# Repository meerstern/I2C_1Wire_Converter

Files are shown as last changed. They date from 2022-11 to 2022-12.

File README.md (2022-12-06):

# I2C-1Wireマスタ変換基板
I2C_1Wire_Converter with DS2485

## 概要
  * [DS2485][1]とレベル変換回路を搭載したI2C-1Wireマスタ変換基板です  
  * I2Cスレーブを1Wireマスタに変換します  
  * タイミングがシビアな1WireデバイスをI2Cコマンドで容易に操作することが可能です  
  * DS2485のレジスタを変更することで1Wire通信のタイミングを細かく調整することが可能です  
  * DS2485は126バイトのバッファを備えており、効率良く1Wire通信をすることが可能です  
  * 本変換基板にはレベル変換回路を搭載しているため、5VレベルのI2C及び1Wireに対応しています  
  * DS2485のGPIOは電源入力のPchMOSFETに接続されています  
  * 電源入力のPchMOSFETを介して1Wireバスの強力プルアップを利用することが可能です  
  * I2Cの接続はGrove互換コネクタを使用しています  
  * 1Wireの接続はVCC、1Wire、GNDの2.54mmピッチターミナルコネクタを使用しています  
  * 1Wireの電源及び信号電圧レベルはGroveコネクタから供給する電源電圧に一致します  
  * 電源電圧：3.3V~5V
  * 基板サイズ25mm x30mm、固定穴M3x2 幅19mm
  
 ## 販売サイト
  * [スイッチサイエンス][2]
  
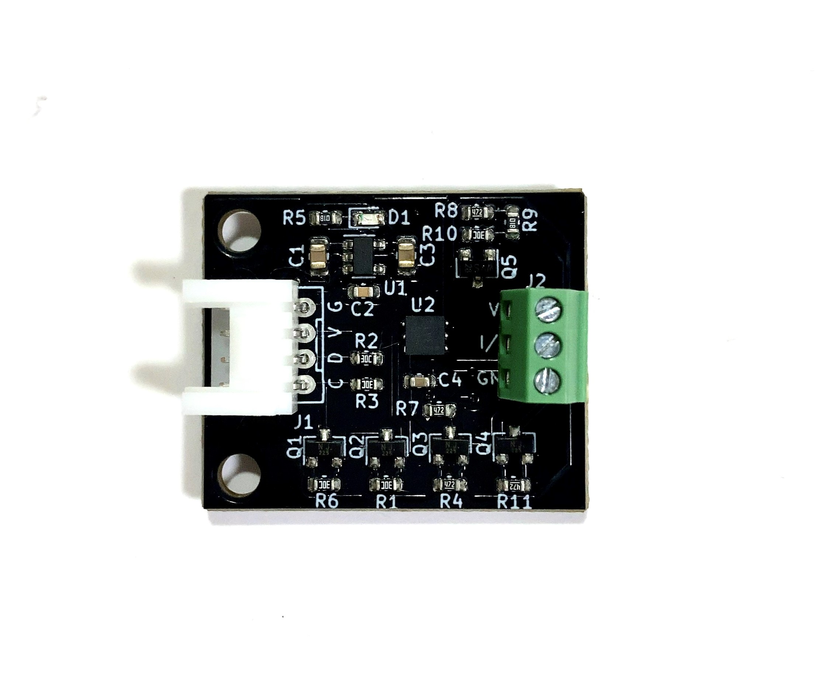
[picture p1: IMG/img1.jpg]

   
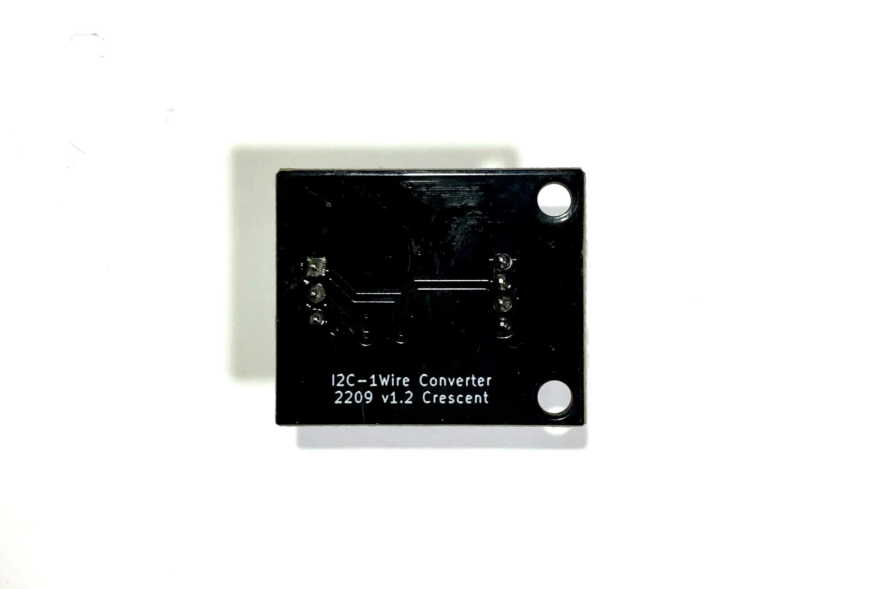
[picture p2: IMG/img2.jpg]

  
[1]: https://www.maximintegrated.com/jp/products/ibutton-one-wire/memory-products/DS2485.html
[2]: https://www.switch-science.com/products/8650

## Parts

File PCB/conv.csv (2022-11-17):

ID | 参照記号 | パッケージ | 数 | 名称 | Supplier and ref
1 | R11,R8,R7,R4 | R_0603_1608Metric | 4 | 4.7k
2 | R10,R6,R1,R3,R2 | R_0603_1608Metric | 5 | 10k
3 | R9,R5 | R_0603_1608Metric | 2 | 1k
4 | Q5 | SOT-23 | 1 | Q_PMOS_GSD
5 | Q4,Q3,Q2,Q1 | SOT-23 | 4 | Q_NMOS_GSD
6 | REF2,REF1 | MountingHole_3.2mm_M3 | 2 | MountingHole_3.2mm_M3
7 | U2 | TDFN6-EP | 1 | ds2485
8 | U1 | SOT-23-5 | 1 | LD3985M33R_SOT23
9 | J2 | PinHeader_1x03_P2.54mm_Vertical | 1 | Conn_01x03
10 | J1 | GROVE | 1 | Conn_01x04
11 | D1 | LED_0603_1608Metric | 1 | LED
12 | C4 | C_0603_1608Metric | 1 | 0.1u
13 | C3,C1 | C_0805_2012Metric | 2 | 10u
14 | C2 | C_0603_1608Metric | 1 | 0.01u

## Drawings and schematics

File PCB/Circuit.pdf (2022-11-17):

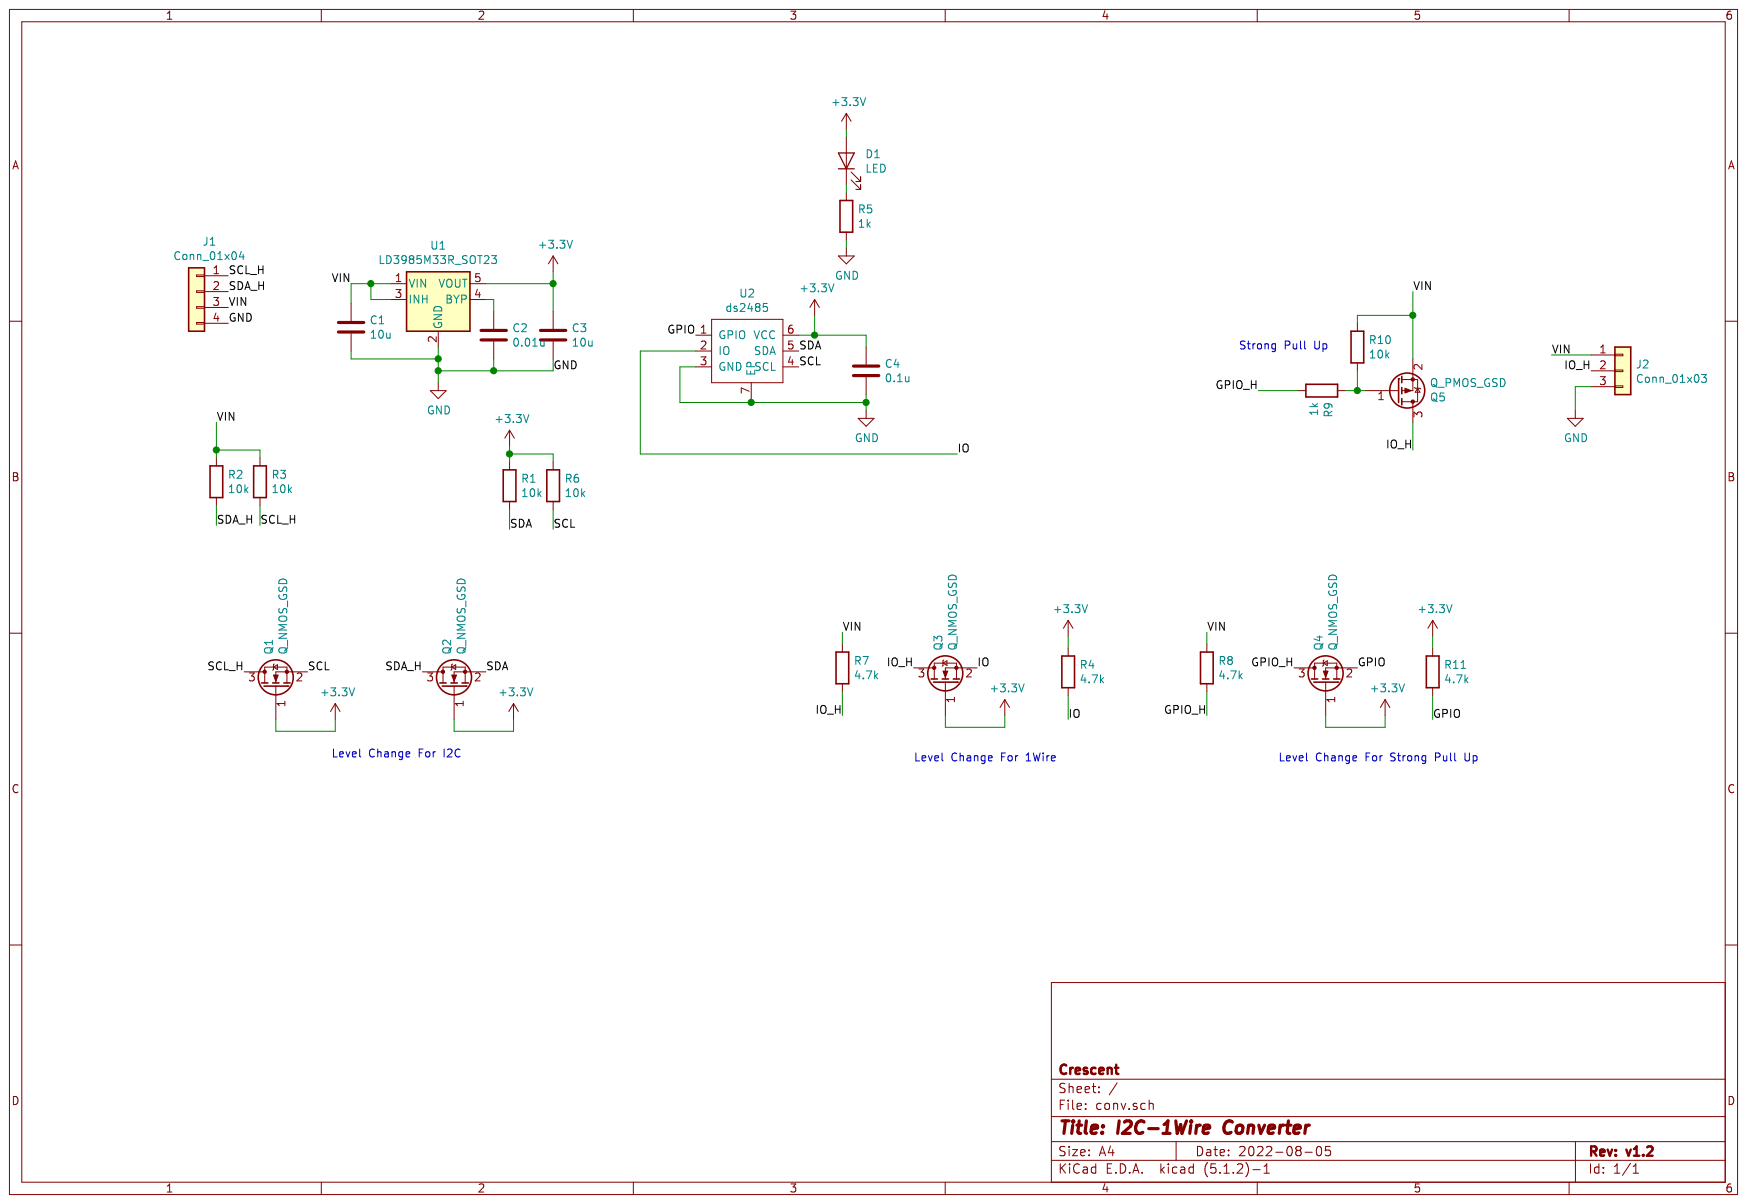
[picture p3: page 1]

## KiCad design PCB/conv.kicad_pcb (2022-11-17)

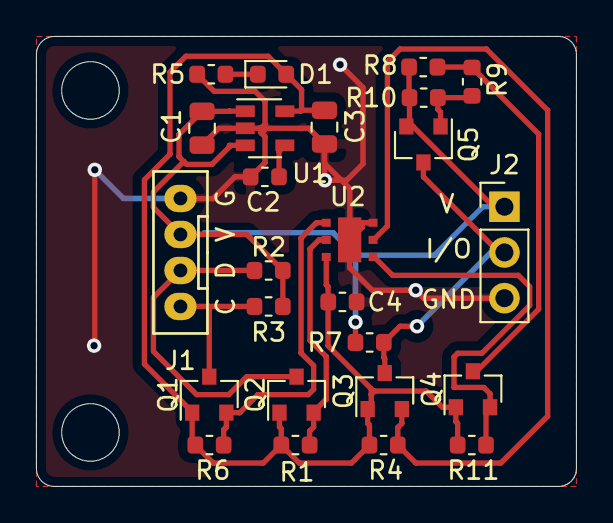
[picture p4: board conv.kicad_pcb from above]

Board: 2 copper layers, 30.0 x 25.0 mm, 27 parts (0 on the bottom side), 14 nets.

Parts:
C1, C3: 10u; C_0805_2012Metric
C2: 0.01u; C_0603_1608Metric
C4: 0.1u; C_0603_1608Metric
D1: LED; LED_0603_1608Metric
J1: Conn_01x04; GROVE
J2: Conn_01x03; PinHeader_1x03_P2.54mm_Vertical
Q1, Q2, Q3, Q4: Q_NMOS_GSD; SOT-23
Q5: Q_PMOS_GSD; SOT-23
R1, R2, R3, R6, R10: 10k; R_0603_1608Metric
R4, R7, R8, R11: 4.7k; R_0603_1608Metric
R5, R9: 1k; R_0603_1608Metric
REF1, REF2: MountingHole_3.2mm_M3
U1: LD3985M33R_SOT23; SOT-23-5
U2: ds2485; TDFN6-EP

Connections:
+3V3: C3.1, C4.1, D1.2, Q1.1, Q2.1, Q3.1, Q4.1, R1.1, R4.1, R6.1, R11.1, U1.5, U2.6
/GPIO: Q4.2, R11.2, U2.1
/GPIO_H: Q4.3, R8.2, R9.2
/IO: Q3.2, R4.2, U2.2
/IO_H: J2.2, Q3.3, Q5.3, R7.2
/SCL: Q1.2, R6.2, U2.4
/SCL_H: J1.1, Q1.3, R3.2
/SDA: Q2.2, R1.2, U2.5
/SDA_H: J1.2, Q2.3, R2.2
/VIN: C1.1, J1.3, J2.1, Q5.2, R2.1, R3.1, R7.1, R8.1, R10.1, U1.1, U1.3
GND: C1.2, C2.2, C3.2, C4.2, J1.4, J2.3, R5.2, U1.2, U2.3, U2.7
unnamed: C2.1, U1.4
unnamed: D1.1, R5.1
unnamed: Q5.1, R9.1, R10.2

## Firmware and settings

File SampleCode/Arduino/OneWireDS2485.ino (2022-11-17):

#include <Arduino.h>
#include <Wire.h>

#define DS2485_ADDRESS  0x40
#define ONE_WIRE_MAX_SEARCH_NUM 10
#define ONE_WIRE_ID_LENGTH      8

struct OneWireDevice {
  uint8_t id[ONE_WIRE_ID_LENGTH];
  float temp;
};

uint8_t       foundDeviceNum=0;
OneWireDevice OneWireDev[ONE_WIRE_MAX_SEARCH_NUM];

void DS2485_WriteData(uint8_t *data, uint8_t dsize)
{
  Wire.beginTransmission(DS2485_ADDRESS);
  Wire.write(data,dsize);
  Wire.endTransmission(1);
  delay(1);
}

void DS2485_ReadData(uint8_t *data, uint8_t dsize)
{
  uint8_t index;
  Wire.requestFrom((uint8_t)(DS2485_ADDRESS), (uint8_t)dsize);
  while (Wire.available()&& index<dsize) 
  {
    *(data+index)=Wire.read();
    index++;
  }

}

void DS2485_Reset()
{
  uint8_t wdata[1]={0x62};
  DS2485_WriteData(wdata,1);
}

void DS2485_SetRPUP()
{
  uint8_t wdata[5]={0x99,0x03,0x11,0x06,0x00};
  DS2485_WriteData(wdata,5);
}

bool DS2485_CheckResult()
{
  uint8_t rdata[2];
  DS2485_ReadData(rdata,2);

  if(rdata[1]==0xAA)
    return true;
  else
    return false;
}

bool DS2485_SearchOneDevice()
{
  uint8_t wdata[4]={0x11,0x02,0b00000101,0xF0};
  uint8_t rdata[11]={0x00};
  bool hasNextDevice=false;
  String id="";

  if(foundDeviceNum>=ONE_WIRE_MAX_SEARCH_NUM)
    return false;
  
  DS2485_WriteData(wdata,4);
  delay(500);  
  DS2485_ReadData(rdata,11);

  if(rdata[1]==0xAA)
  {
    id= String(rdata[2], 16) + ":"
        + String(rdata[3], 16) + ":"
        + String(rdata[4], 16) + ":"
        + String(rdata[5], 16) + ":"
        + String(rdata[6], 16) + ":"
        + String(rdata[7], 16) + ":"
        + String(rdata[8], 16) + ":"
        + String(rdata[9], 16) ;
    Serial.print("Found Device:");
    Serial.println(id);
    if(rdata[10]==0)
      hasNextDevice=true;

    OneWireDev[foundDeviceNum].id[0]=rdata[2];
    OneWireDev[foundDeviceNum].id[1]=rdata[3];
    OneWireDev[foundDeviceNum].id[2]=rdata[4];
    OneWireDev[foundDeviceNum].id[3]=rdata[5];
    OneWireDev[foundDeviceNum].id[4]=rdata[6];
    OneWireDev[foundDeviceNum].id[5]=rdata[7];
    OneWireDev[foundDeviceNum].id[6]=rdata[8];
    OneWireDev[foundDeviceNum].id[7]=rdata[9];
    foundDeviceNum++;
  }
  return hasNextDevice;
}

bool DS2485_SearchNextDevice()
{
  uint8_t wdata[4]={0x11,0x02,0b00000001,0xF0};
  uint8_t rdata[11]={0x00};
  bool hasNextDevice=false;
  String id="";

  if(foundDeviceNum>=ONE_WIRE_MAX_SEARCH_NUM)
    return false;
  
  DS2485_WriteData(wdata,4);
  delay(500);   
  DS2485_ReadData(rdata,11);

  if(rdata[1]==0xAA)
  {
    id= String(rdata[2], 16) + ":"
        + String(rdata[3], 16) + ":"
        + String(rdata[4], 16) + ":"
        + String(rdata[5], 16) + ":"
        + String(rdata[6], 16) + ":"
        + String(rdata[7], 16) + ":"
        + String(rdata[8], 16) + ":"
        + String(rdata[9], 16) ;
    Serial.print("Found Device:");
    Serial.println(id);
    if(rdata[10]==0)
      hasNextDevice=true;

    OneWireDev[foundDeviceNum].id[0]=rdata[2];
    OneWireDev[foundDeviceNum].id[1]=rdata[3];
    OneWireDev[foundDeviceNum].id[2]=rdata[4];
    OneWireDev[foundDeviceNum].id[3]=rdata[5];
    OneWireDev[foundDeviceNum].id[4]=rdata[6];
    OneWireDev[foundDeviceNum].id[5]=rdata[7];
    OneWireDev[foundDeviceNum].id[6]=rdata[8];
    OneWireDev[foundDeviceNum].id[7]=rdata[9];
    foundDeviceNum++;
  }
  return hasNextDevice;
}

void DS2485_GetTempFromDS18B20(uint8_t index)
{
  uint8_t reset[4]={0x88,0x02,0x00,0b10000010};  
  uint8_t match[4]={0x88,0x02,0x03,0x55};
  uint8_t romid[12]={0x88,0x0A,0x09,0x08,0x00,0x00,0x00,0x00,0x00,0x00,0x00,0x00};
  uint8_t convt[4]={0x88,0x02,0x03,0x44};
  uint8_t rscrt[4]={0x88,0x02,0x03,0xBE};//Read scratchpad
  uint8_t rbyte[4]={0x88,0x02,0x08,0x09};//Read byte
  uint8_t rdata[12]={0x00};
  float tempf=0.0f;
  romid[4]=OneWireDev[index].id[0];
  romid[5]=OneWireDev[index].id[1];
  romid[6]=OneWireDev[index].id[2];
  romid[7]=OneWireDev[index].id[3];
  romid[8]=OneWireDev[index].id[4];
  romid[9]=OneWireDev[index].id[5];
  romid[10]=OneWireDev[index].id[6];
  romid[11]=OneWireDev[index].id[7];
  
  DS2485_WriteData(reset,4);
  delay(5); 
  DS2485_WriteData(match,4);
  delay(5);  
  DS2485_WriteData(romid,12); 
  delay(5); 
  DS2485_WriteData(convt,4);
  delay(750);
  DS2485_WriteData(reset,4); 
  delay(5); 
  DS2485_WriteData(match,4); 
  delay(5); 
  DS2485_WriteData(romid,12);  
  delay(5); 
  DS2485_WriteData(rscrt,4); 
  delay(5);  
  DS2485_WriteData(rbyte,4); 
  delay(5);  
  DS2485_ReadData(rdata,12);
  delay(5); 
  uint16_t tmpByte=(uint16_t)rdata[5]*256+(uint16_t)rdata[4];
  if(tmpByte&0xF800)
    tempf=-1.0*((~tmpByte+1)*0.0625);
  else
    tempf=tmpByte*0.0625;
  OneWireDev[index].temp=tempf;

  Serial.print("Index:");
  Serial.print(index);
  Serial.print(", Temp:");
  Serial.println(tempf);
}

void setup() 
{
  Wire.begin();
  Wire.setClock(100000);
  Serial.begin(9600);
  Serial.println("Start DS2485 & 1-Wire Temp Sensor Read");
  DS2485_Reset();
  if(DS2485_CheckResult()==false)
  {
    Serial.println("Err Not Found DS2485. Check Connections!");
    while(1);
  }
  DS2485_SetRPUP();
  if(DS2485_CheckResult()==false)
  {
    Serial.println("Err Failed Setting of DS2485.");
    while(1);
  }
  
  foundDeviceNum=0;  
  Serial.println("***1-Wire Device Search Start***");
  if(DS2485_SearchOneDevice()==true)
  {
    while(DS2485_SearchNextDevice());
  }
  Serial.println("***1-Wire Device Search End***");

};

void loop() 
{

    for(uint8_t i=0; i<foundDeviceNum; i++)
    {
      DS2485_GetTempFromDS18B20(i);
      delay(10);
    }
    delay(1000);  

};

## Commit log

2022-11-17 Add Sample Code
2022-11-17 Add PCB
    [conv-B_Cu.gbl, conv-B_Mask.gbs, conv-B_Paste.gbp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]
